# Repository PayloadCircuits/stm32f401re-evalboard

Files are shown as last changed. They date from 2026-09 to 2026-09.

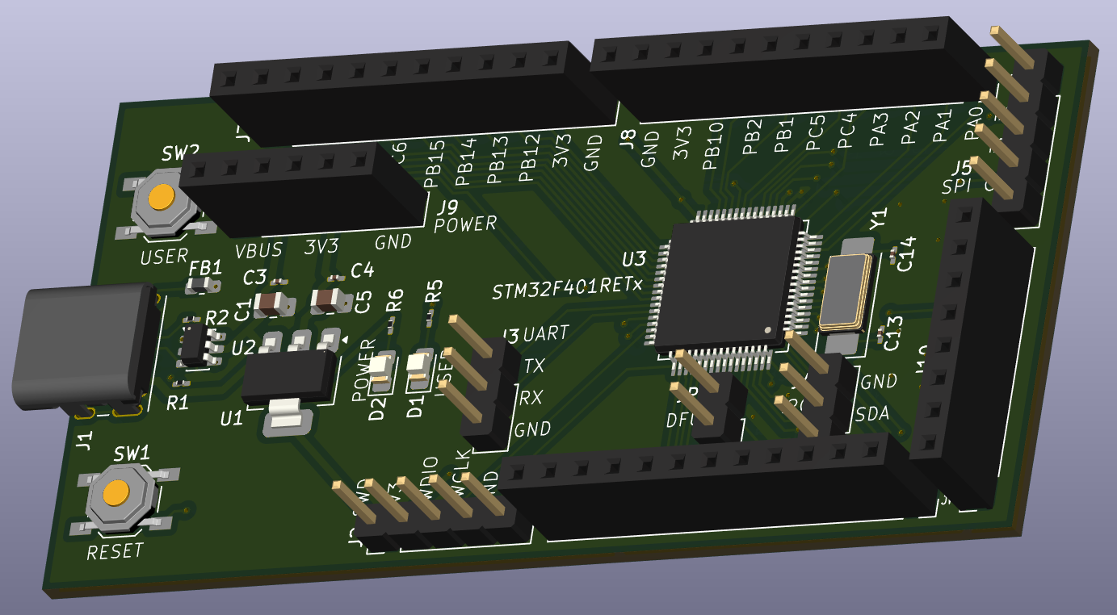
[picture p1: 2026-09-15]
Screenshot 2026-09-03 185238.png

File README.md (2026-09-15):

# STM32F401RE Evaluation Board
Two-layer STM32F401RE (LQFP64) evaluation board designed in KiCad, built as
a solo entry for the **Mixed Traces PCB Design Competition**, hosted by
Mixed Signals (Electronics Association of MEC).

# Overview
A compact, self-contained STM32F401RE dev board inspired by the
NUCLEO-F401RE reference design, built to fit within a 100mm x 100mm,
two-layer PCB. Per the competition rules, an on-board ST-LINK debugger is
not required — programming and debugging are handled through an external
SWD header instead.

## Features
- STM32F401RET6 (LQFP64) microcontroller
- USB-C power input with CC1/CC2 pull-downs and USBLC6-2SC6 ESD protection
- NCP1117-3.3 LDO regulation
- 8MHz HSE crystal (derives both the 84MHz system clock and 48MHz USB clock)
- External SWD header for programming/debugging
- UART, SPI, and I2C headers
- 34 GPIO broken out across four expansion headers, each with 3V3/GND
  reference pins
- Dedicated power breakout header (VBUS, 3V3, GND)
- User + reset buttons, user + power LEDs
- Full ground plane pour on both copper layers

# Tools
Designed entirely in [KiCad](https://www.kicad.org/) 9.

# Schematic
- https://github.com/PayloadCircuits/stm32f401re-evalboard/blob/main/Screenshot%202026-09-03%20185406.png
- https://github.com/PayloadCircuits/stm32f401re-evalboard/blob/main/schematic.pdf

# PCB Layout
https://github.com/PayloadCircuits/stm32f401re-evalboard/blob/main/Screenshot%202026-09-03%20184711.png

# Gerber
https://github.com/PayloadCircuits/stm32f401re-evalboard/blob/main/GERBER.zip

# Render Images
- https://github.com/PayloadCircuits/stm32f401re-evalboard/blob/main/Screenshot%202026-09-03%20185029.png
- https://github.com/PayloadCircuits/stm32f401re-evalboard/blob/main/Screenshot%202026-09-03%20185117.png
- https://github.com/PayloadCircuits/stm32f401re-evalboard/blob/main/Screenshot%202026-09-03%20185238.png

# BOM with estimated component cost
https://github.com/PayloadCircuits/stm32f401re-evalboard/blob/main/BOM%20estimate.pdf

# ERC and DRC results
- https://github.com/PayloadCircuits/stm32f401re-evalboard/blob/main/Screenshot%202026-09-15%20185338.png
- https://github.com/PayloadCircuits/stm32f401re-evalboard/blob/main/Screenshot%202026-09-15%20185429.png

# Status
Entered in the Mixed Traces PCB Design Competition — progress checkpoint
submitted 5 September 2026, final submission due 15 September 2026.

# License
Hardware design files in this repository are licensed under the
[CERN Open Hardware Licence Version 2 - Permissive (CERN-OHL-P-2.0)](LICENSE).

# Author
Adarsh S — [Payload Circuits](https://github.com/PayloadCircuits)

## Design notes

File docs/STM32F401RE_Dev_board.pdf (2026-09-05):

# | Reference Qty | Value | DNP | Exclude from BOM Exclude from Board Footprint Datasheet Description

1 C1,C5,C17 | 3 10uf | Capacitor_SMD:C_0805_2012Metric_Pad1.18x1.45mm_HandSolder ~ | Polarized capacitor
2 C2,C3,C4,C6,C7,C8,C9,C12,C15 9 0.1uf | Capacitor_SMD:C_0201_0603Metric_Pad0.64x0.40mm_HandSolder ~ | Unpolarized capacitor
3 C10 | 1 1uf | Capacitor_SMD:C_0805_2012Metric_Pad1.18x1.45mm_HandSolder ~ | Polarized capacitor
4 C11 | 1 2.2uf | Capacitor_SMD:C_0805_2012Metric_Pad1.18x1.45mm_HandSolder ~ | Unpolarized capacitor
5 C13,C14 | 2 22pf | Capacitor_SMD:C_0201_0603Metric_Pad0.64x0.40mm_HandSolder ~ | Unpolarized capacitor
6 D1 | 1 LED_user | LED_SMD:LED_0805_2012Metric_Pad1.15x1.40mm_HandSolder ~ | Light emitting diode
7 D2 | 1 LED_PWR | LED_SMD:LED_0805_2012Metric_Pad1.15x1.40mm_HandSolder ~ | Light emitting diode
8 FB1,FB2 | 2 FerriteBead_Small | Inductor_SMD:L_0603_1608Metric_Pad1.05x0.95mm_HandSolder ~ | Ferrite bead, small symbol
9 J1 | 1 USB_C_Receptacle_USB2.0_14P | Connector_USB:USB_C_Receptacle_GCT_USB4085 https://www.usb.org/sites/default/files/documents/usb_type-c.zip USB 2.0-only 14P Type-C Receptacle connector
10 J2 | 1 SWD | Connector_PinHeader_1.00mm:PinHeader_1x05_P1.00mm_Vertical ~ | Generic connector, single row, 01x05, script generated
11 J3 | 1 UART | Connector_PinHeader_1.00mm:PinHeader_1x03_P1.00mm_Vertical ~ | Generic connector, single row, 01x03, script generated
12 J4 | 1 I2C | Connector_PinHeader_1.00mm:PinHeader_1x03_P1.00mm_Vertical ~ | Generic connector, single row, 01x03, script generated
13 J5 | 1 SPI | Connector_PinHeader_1.00mm:PinHeader_1x05_P1.00mm_Vertical ~ | Generic connector, single row, 01x05, script generated
14 J6 | 1 GPIO_A | Connector_PinSocket_1.00mm:PinSocket_1x12_P1.00mm_Vertical ~ | Generic connector, single row, 01x12, script generated
15 J7 | 1 GPIO_B | Connector_PinSocket_1.00mm:PinSocket_1x11_P1.00mm_Vertical ~ | Generic connector, single row, 01x11, script generated
16 J8 | 1 GPIO_C | Connector_PinSocket_1.00mm:PinSocket_1x11_P1.00mm_Vertical ~ | Generic connector, single row, 01x11, script generated
17 J9 | 1 POWER | Connector_PinSocket_1.00mm:PinSocket_1x06_P1.00mm_Vertical ~ | Generic connector, single row, 01x06, script generated
18 J10 | 1 GPIO_D | Connector_PinSocket_1.00mm:PinSocket_1x08_P1.00mm_Vertical ~ | Generic connector, single row, 01x08, script generated
19 JP1 | 1 DFU | TestPoint:TestPoint_2Pads_Pitch5.08mm_Drill1.3mm ~ | Jumper, 2-pole, open
20 R1,R2 | 2 5.1K | Resistor_SMD:R_0201_0603Metric_Pad0.64x0.40mm_HandSolder ~ | Resistor
21 R3,R4 | 2 10K | Resistor_SMD:R_0201_0603Metric_Pad0.64x0.40mm_HandSolder ~ | Resistor
22 R5,R6 | 2 470R | Resistor_SMD:R_0201_0603Metric_Pad0.64x0.40mm_HandSolder ~ | Resistor
23 R7,R8 | 2 4.7K | Resistor_SMD:R_0201_0603Metric_Pad0.64x0.40mm_HandSolder ~ | Resistor
24 SW1 | 1 SW_RST | Button_Switch_SMD:SW_SPST_TL3342 ~ | Push button switch, generic, two pins
25 SW2 | 1 SW_user | Button_Switch_SMD:SW_SPST_TL3342 ~ | Push button switch, generic, two pins
26 U1 | 1 NCP1117-3.3_SOT223 | Package_TO_SOT_SMD:SOT-223-3_TabPin2 http://www.onsemi.com/pub_link/Collateral/NCP1117-D.PDF 1A Low drop-out regulator, Fixed Output 3.3V, SOT-223
27 U2 | 1 USBLC6-2SC6 | Package_TO_SOT_SMD:SOT-23-6 https://www.st.com/resource/en/datasheet/usblc6-2.pdf Very low capacitance ESD protection diode, 2 data-line, SOT-23-6
28 U3 | 1 STM32F401RETx | Package_QFP:LQFP-64_10x10mm_P0.5mm https://www.st.com/resource/en/datasheet/stm32f401re.pdf STMicroelectronics Arm Cortex-M4 MCU, 512KB flash, 96KB RAM, 84 MHz, 1.7-3.6V, 50 GPIO, LQFP64
29 Y1 | 1 8MHz | Crystal:Crystal_SMD_0603-2Pin_6.0x3.5mm_HandSoldering ~ | Two pin crystal, small symbol

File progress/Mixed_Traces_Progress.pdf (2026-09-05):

# Mixed Traces PCB Design Competition

## Progress Evaluation Submission — 3 September 2026

## STM32F401RE Evaluation Board

### by Payload Circuits Adarsh S — Solo Entry

## 1. Selected MCU and Design Concept

The fixed microcontroller for this competition is the STM32F401RET6 (LQFP64), as required by the brief. The design concept is a compact, self-contained STM32F401RE evaluation board inspired by the NUCLEO-F401RE reference, built to fit within a 100mm × 100mm, two-layer PCB.

Per the competition rules, the on-board ST-LINK debugger is explicitly not required, which simplified the design considerably compared to the Nucleo reference — programming and debugging are handled through a standard external SWD header rather than an on-board programmer IC. This freed up board area and routing complexity that was redirected toward a more generous GPIO expansion header set.

The design philosophy prioritized correctness and routing/documentation quality (the criteria weighted most heavily in evaluation) over chasing extremes in size or cost, and favored “smart” flexibility — a single, wellexecuted power path and full signal breakout to headers — over redundant ports or power-input options that would add cost and routing complexity without improving the score.

## 2. Block Diagram

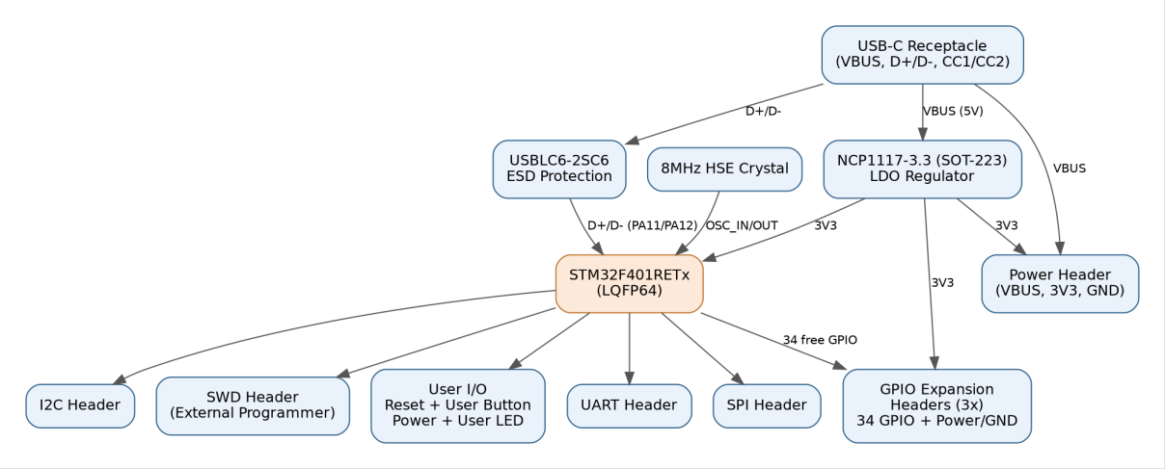
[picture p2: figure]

Figure 1: System block diagram — power, USB, MCU, and header breakout

## 3. Schematic Progress

The schematic is complete and passes ERC with zero unresolved violations.

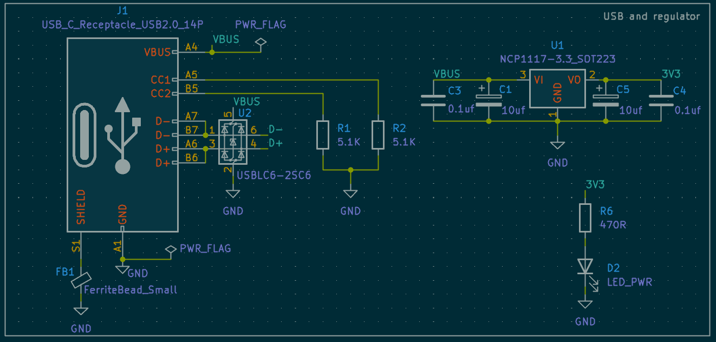
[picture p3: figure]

Figure 2: USB-C input, ESD protection, and 3.3V regulation

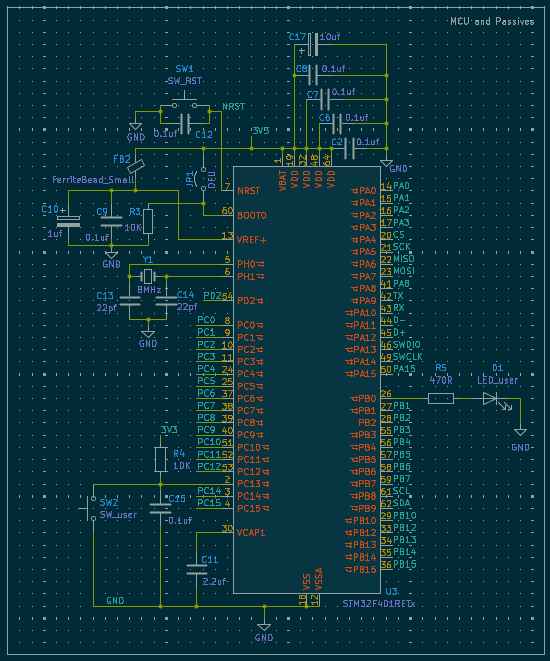
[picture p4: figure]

Figure 3: STM32F401RE core — decoupling, VCAP, reset, BOOT0/DFU, and HSE crystal

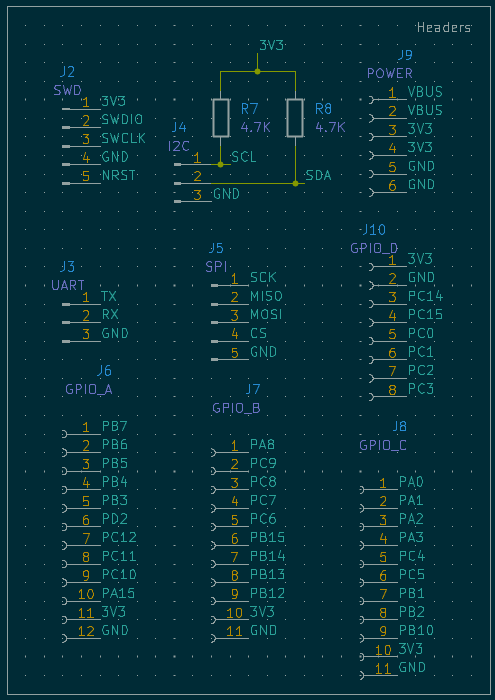
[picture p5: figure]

Figure 4: SWD, UART, SPI, I2C, POWER and GPIO expansion header breakout

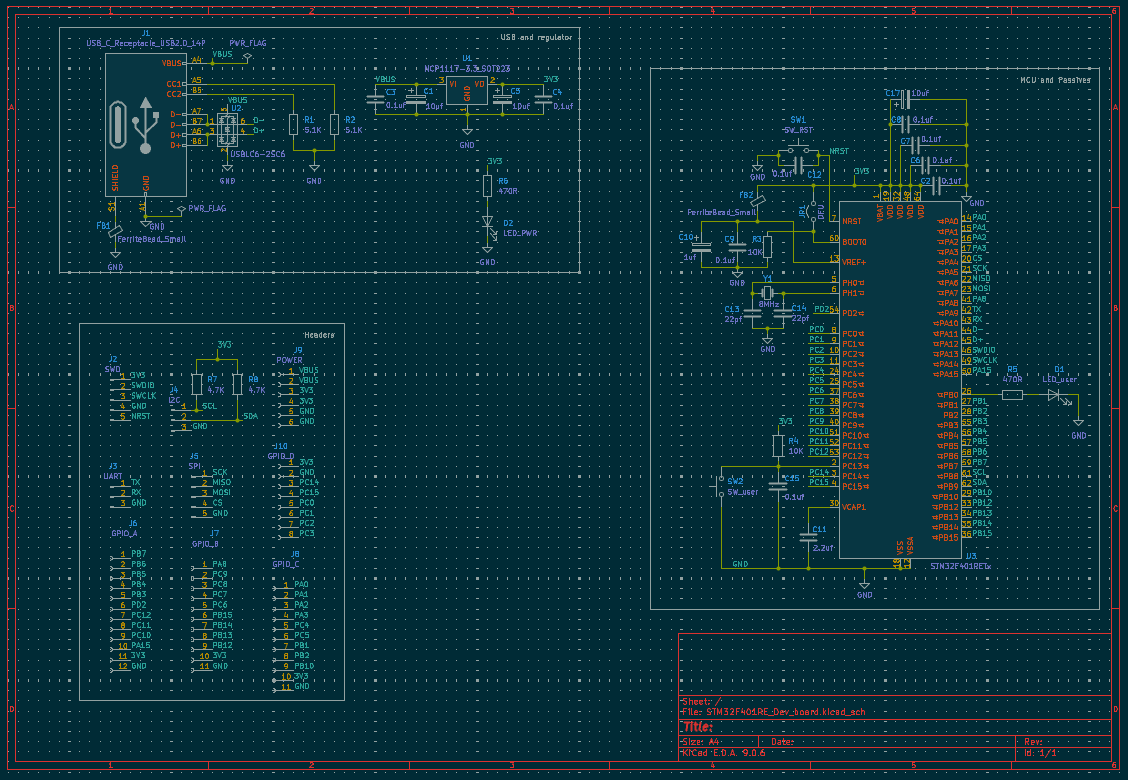
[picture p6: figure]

Figure 5: Complete Schematic diagram

## 4. Component Selection

Key components and the reasoning behind each selection:

Function | Part / Choice | Package | Rationale
MCU | STM32F401RETx | LQFP64 | Fixed by competition rules
Voltage regulator | NCP1117-3.3 (ST suffix) | SOT-223 | Simple fixed-3.3V LDO, adequate for MCU + peripheral current draw, no external feedback network needed
USB connector | USB-C receptacle, full THT (signal + shield legs) | THT, 2-layer footprint | Mechanically robust for repeated insertion; design-only competition so hand-solder ease was not a constraint
USB ESD protection | USBLC6-2SC6 | SOT-23-6 | Low-capacitance ESD array for D+/D-lines, standard practice for USB2.0 device ports
HSE crystal | 8MHz, 22pF load caps | SMD 3.5x6mm, hand-solder | 8MHz cleanly divides/multiplies to both 84MHz SYSCLK and 48MHz USB clock without fractional PLL math
Passives (R, C ≤100nF) | Generic 0603 | 0603 | Compact, consistent footprint across the board
Bulk/decoupling caps (≥1µF) | Generic ceramic | 0805 | Safer margin against DC-bias derating and hand-solder heat vs 0603
Ferrite beads | Generic SMD ferrite bead | 0603 (L_0603_1608Metric)VDD→VDDA analog isolation
Debug/comms/GPIO headers | 2.54mm pitch, male (SWD/UART/SPI/I2C) & female (GPIO/Power) | THT 2.54mm | Male for probe/ribbon-cable connections; female for shield/jumper-wire compatibility, matching Nucleo convention

## 5. PCB Placement / Routing Progress

Component placement is complete, with connectors distributed across all four board edges for accessible wiring, small passives relocated to the bottom layer to relieve top-layer routing density, and the crystal kept
immediately adjacent to the MCU's oscillator pins. Routing is fully complete on both layers with a poured ground plane, and the board passes DRC with zero unresolved violations (a small number of connector-specific clearance flags were reviewed and excluded — see Section 6).

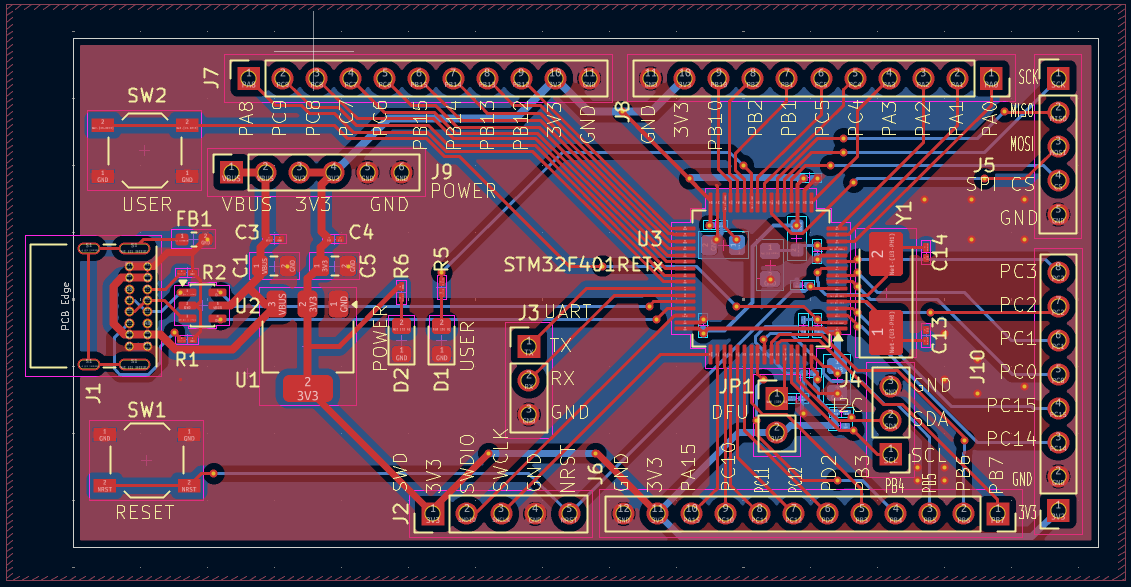
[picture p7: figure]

Figure 5: Completed two-layer routing with ground pour (top view, PCB editor)

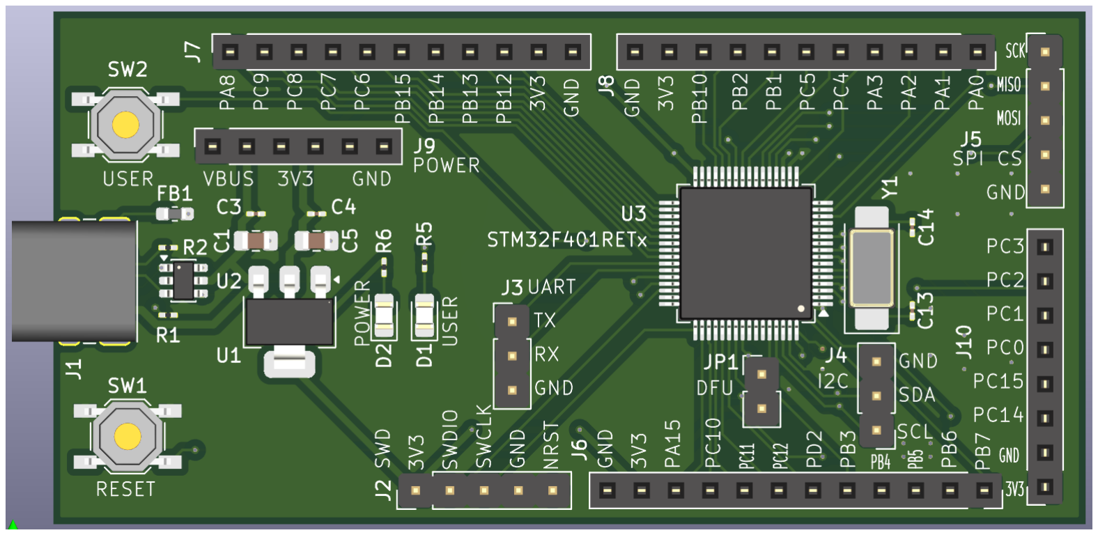
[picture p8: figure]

Figure 6: 3D render, top side

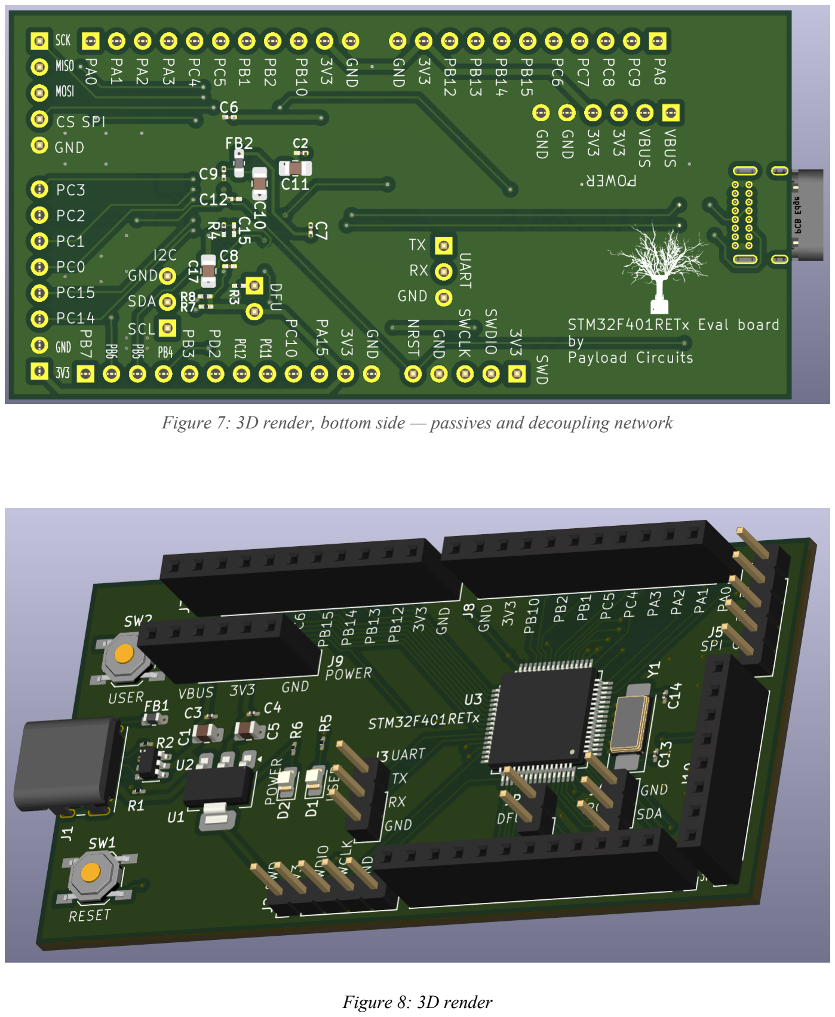
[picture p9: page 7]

Figure 7: 3D render, bottom side — passives and decoupling network

Figure 8: 3D render

## 6. Major Design Decisions

- On-board ST-LINK omitted per competition rules; programming/debugging handled via an external SWD header instead, saving board area and routing for GPIO expansion.
- USB-C power input (no redundant barrel-jack) with CC1/CC2 pull-downs for USB-C power negotiation, keeping the power section simple, low-cost, and low-routing-complexity.
- NCP1117-3.3 in SOT-223 (not SOT-252/DPAK) selected since MCU + peripheral current draw does not need the larger package's added thermal capacity.
- Full through-hole USB-C receptacle (signal and shield legs) chosen over an SMD-only part for greater mechanical durability under repeated cable insertion.
- 8MHz HSE crystal selected specifically because it cleanly derives both the 84MHz system clock and the 48MHz USB clock without fractional PLL configuration.
- All four MCU VDD pins individually decoupled with 100nF capacitors; a single shared 10µF bulk capacitor covers the common VDD net rather than duplicating bulk capacitance at every pin.
- VDDA/VSSA isolated from the main VDD/VSS supply via a ferrite bead on the VDD→VDDA path only, with VSS→VSSA tied directly, following standard STM32 analog-supply practice.
- GPIO expansion split across four headers by port, with 3V3/GND reference pins added to every header — directly satisfying the brief's "power and ground connections through headers" requirement rather than treating it as GPIO-only.
- Small passives (resistors, decoupling/bulk caps, ferrite beads) moved to the bottom copper layer during layout to relieve routing congestion around the MCU on the top layer, while mechanically-interactive parts (connectors, buttons, LEDs, crystal, MCU) remained on top.
- A small number of DRC clearance/thermal-relief flags on the USB-C connector's own footprint (internal pin spacing, F.Fab/Edge.Cuts overlap) were individually reviewed and excluded as expected connector-footprint behavior rather than genuine manufacturing risk; all other violations were resolved by repositioning or adjusting zone connection settings.

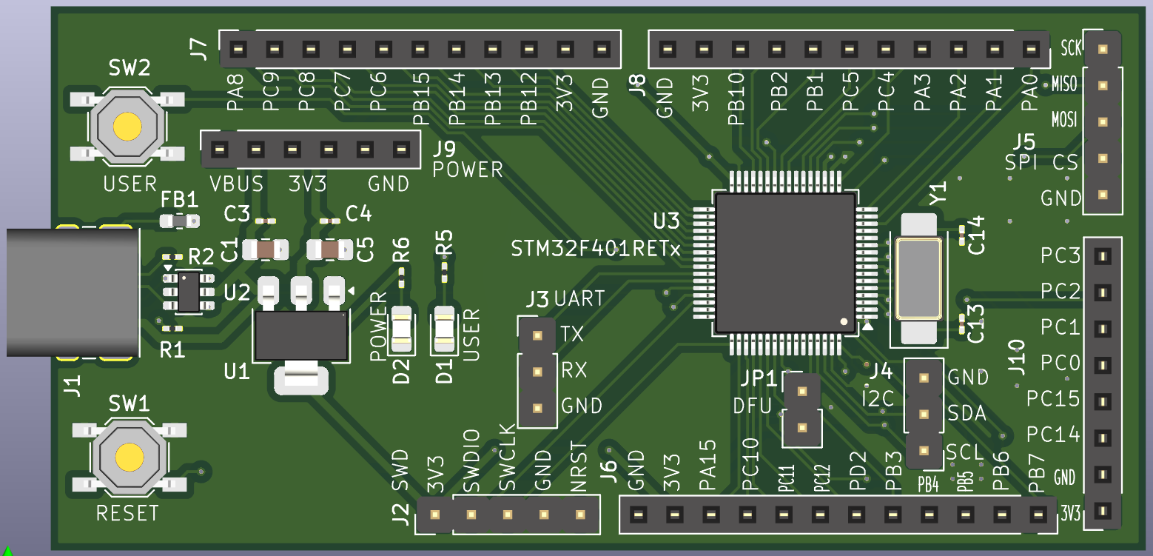
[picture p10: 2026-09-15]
Screenshot 2026-09-03 185029.png

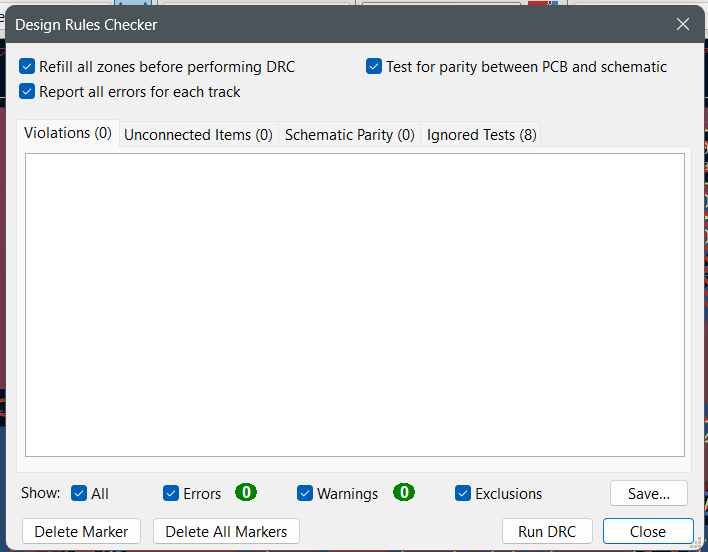
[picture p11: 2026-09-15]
Screenshot 2026-09-15 185429.png

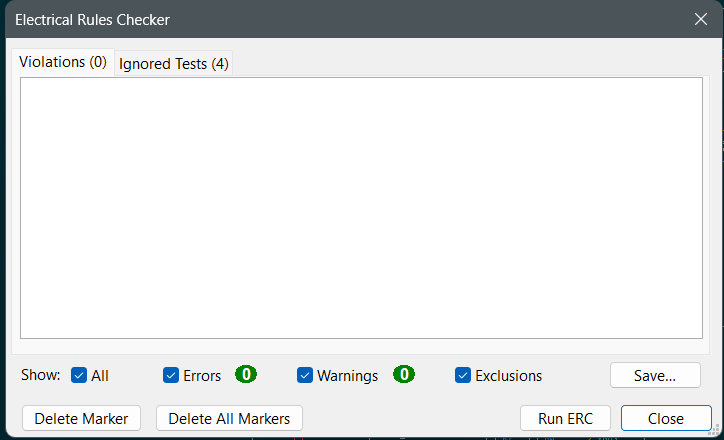
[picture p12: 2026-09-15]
Screenshot 2026-09-15 185338.png

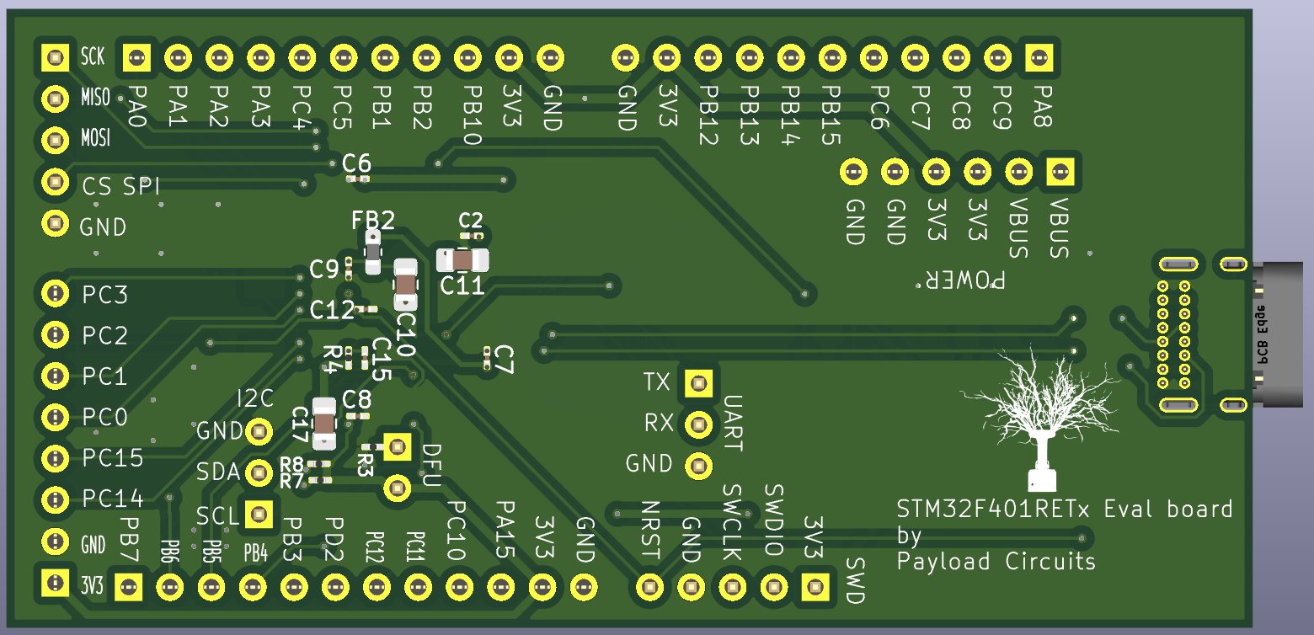
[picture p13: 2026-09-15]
Screenshot 2026-09-03 185117.png

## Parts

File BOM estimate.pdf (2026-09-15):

Id | Designator | Footprint | Quantity Designation | Unit price (₹)
| 1 J2 | PinHeader_1x05_P2.54mm_Vertical | 1 SWD | 10
| 2 C2, C3, C4, C6, C7, C8, C9, C12, C15 | C_0201_0603Metric_Pad0.64x0.40mm_HandSolder | 9 0.1uf | 10
| 3 SW1 | SW_SPST_TL3342 | 1 SW_RST | 55
| 4 U2 | SOT-23-6 | 1 USBLC6-2SC6 | 10
| 5 J10 | PinSocket_1x08_P2.54mm_Vertical | 1 GPIO_D | 10
| 6 C1, C5, C17 | C_0805_2012Metric_Pad1.18x1.45mm_HandSolder | 3 10uf | 15
| 7 SW2 | SW_SPST_TL3342 | 1 SW_user | 55
| 8 Y1 | Crystal_SMD_0603-2Pin_6.0x3.5mm_HandSoldering | 1 8MHz | 60
| 9 R5, R6 | R_0201_0603Metric_Pad0.64x0.40mm_HandSolder | 2 470R | 10
| 10 J6 | PinSocket_1x12_P2.54mm_Vertical | 1 GPIO_A | 10
| 11 FB1, FB2 | L_0603_1608Metric_Pad1.05x0.95mm_HandSolder | 2 FerriteBead_Small | 10
| 12 J7 | PinSocket_1x11_P2.54mm_Vertical | 1 GPIO_B | 10
| 13 J9 | PinSocket_1x06_P2.54mm_Vertical | 1 POWER | 10
| 14 J4 | PinHeader_1x03_P2.54mm_Vertical | 1 I2C | 10
| 15 U3 | LQFP-64_10x10mm_P0.5mm | 1 STM32F401RETx | 350
| 16 J3 | PinHeader_1x03_P2.54mm_Vertical | 1 UART | 10
| 17 R1, R2 | R_0201_0603Metric_Pad0.64x0.40mm_HandSolder | 2 5.1K | 10
| 18 J1 | USB_C_Receptacle_GCT_USB4085 | 1 USB_C_Receptacle_USB2.0_14P | 80
| 19 J5 | PinHeader_1x05_P2.54mm_Vertical | 1 SPI | 10
| 20 D1 | LED_0805_2012Metric_Pad1.15x1.40mm_HandSolder | 1 LED_user | 15
| 21 J8 | PinSocket_1x11_P2.54mm_Vertical | 1 GPIO_C | 10
| 22 D2 | LED_0805_2012Metric_Pad1.15x1.40mm_HandSolder | 1 LED_PWR | 15
| 23 C13, C14 | C_0201_0603Metric_Pad0.64x0.40mm_HandSolder | 2 22pf | 20
| 24 U1 | SOT-223-3_TabPin2 | 1 NCP1117-3.3_SOT223 | 25
| 25 JP1 | PinHeader_1x02_P2.54mm_Vertical | 1 DFU | 10
| 26 C11 | C_0805_2012Metric_Pad1.18x1.45mm_HandSolder | 1 2.2uf | 5
| 27 C10 | C_0805_2012Metric_Pad1.18x1.45mm_HandSolder | 1 1uf | 5
| 28 R3, R4 | R_0201_0603Metric_Pad0.64x0.40mm_HandSolder | 2 10K | 10
| 29 R7, R8 | R_0201_0603Metric_Pad0.64x0.40mm_HandSolder | 2 4.7K | 10

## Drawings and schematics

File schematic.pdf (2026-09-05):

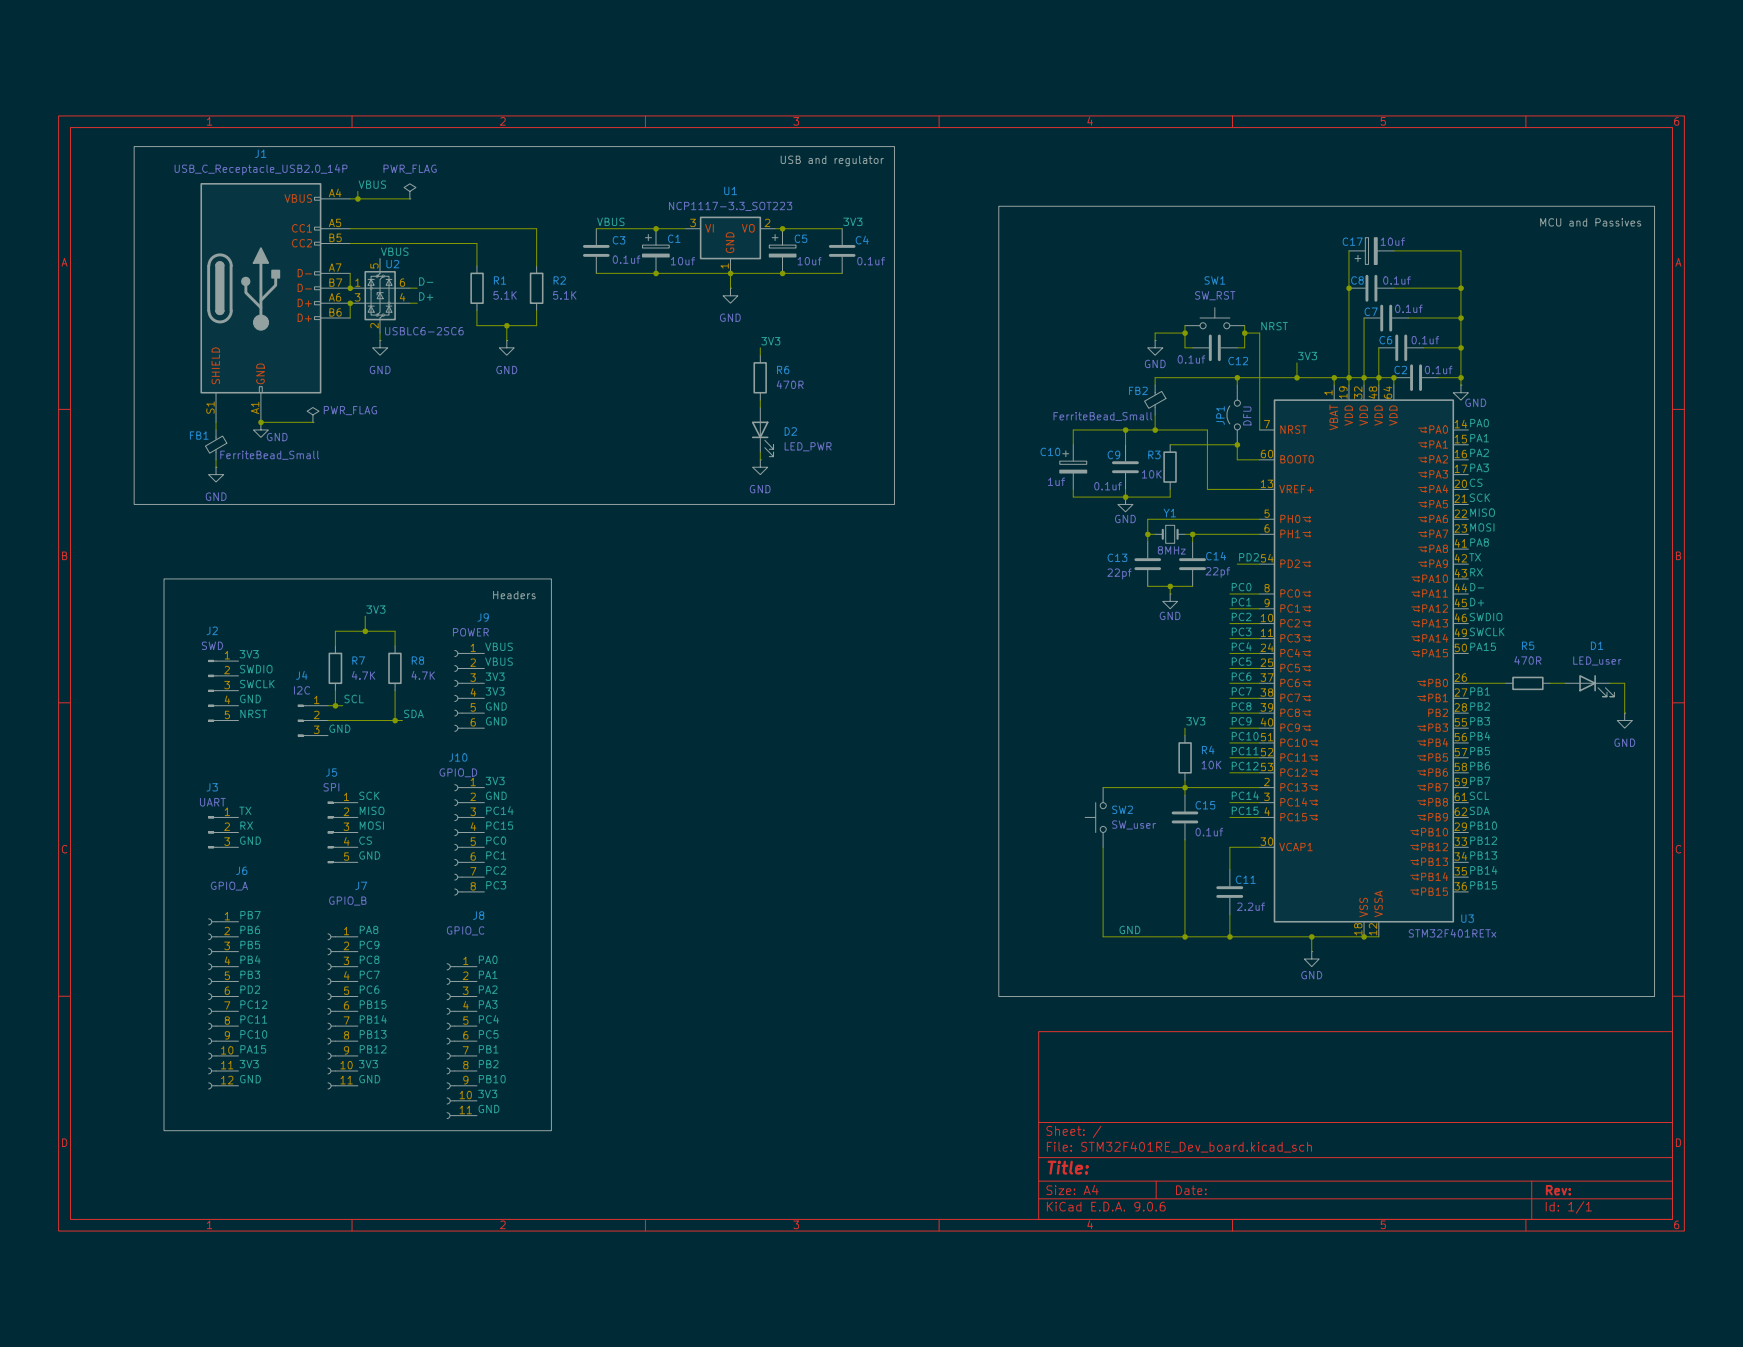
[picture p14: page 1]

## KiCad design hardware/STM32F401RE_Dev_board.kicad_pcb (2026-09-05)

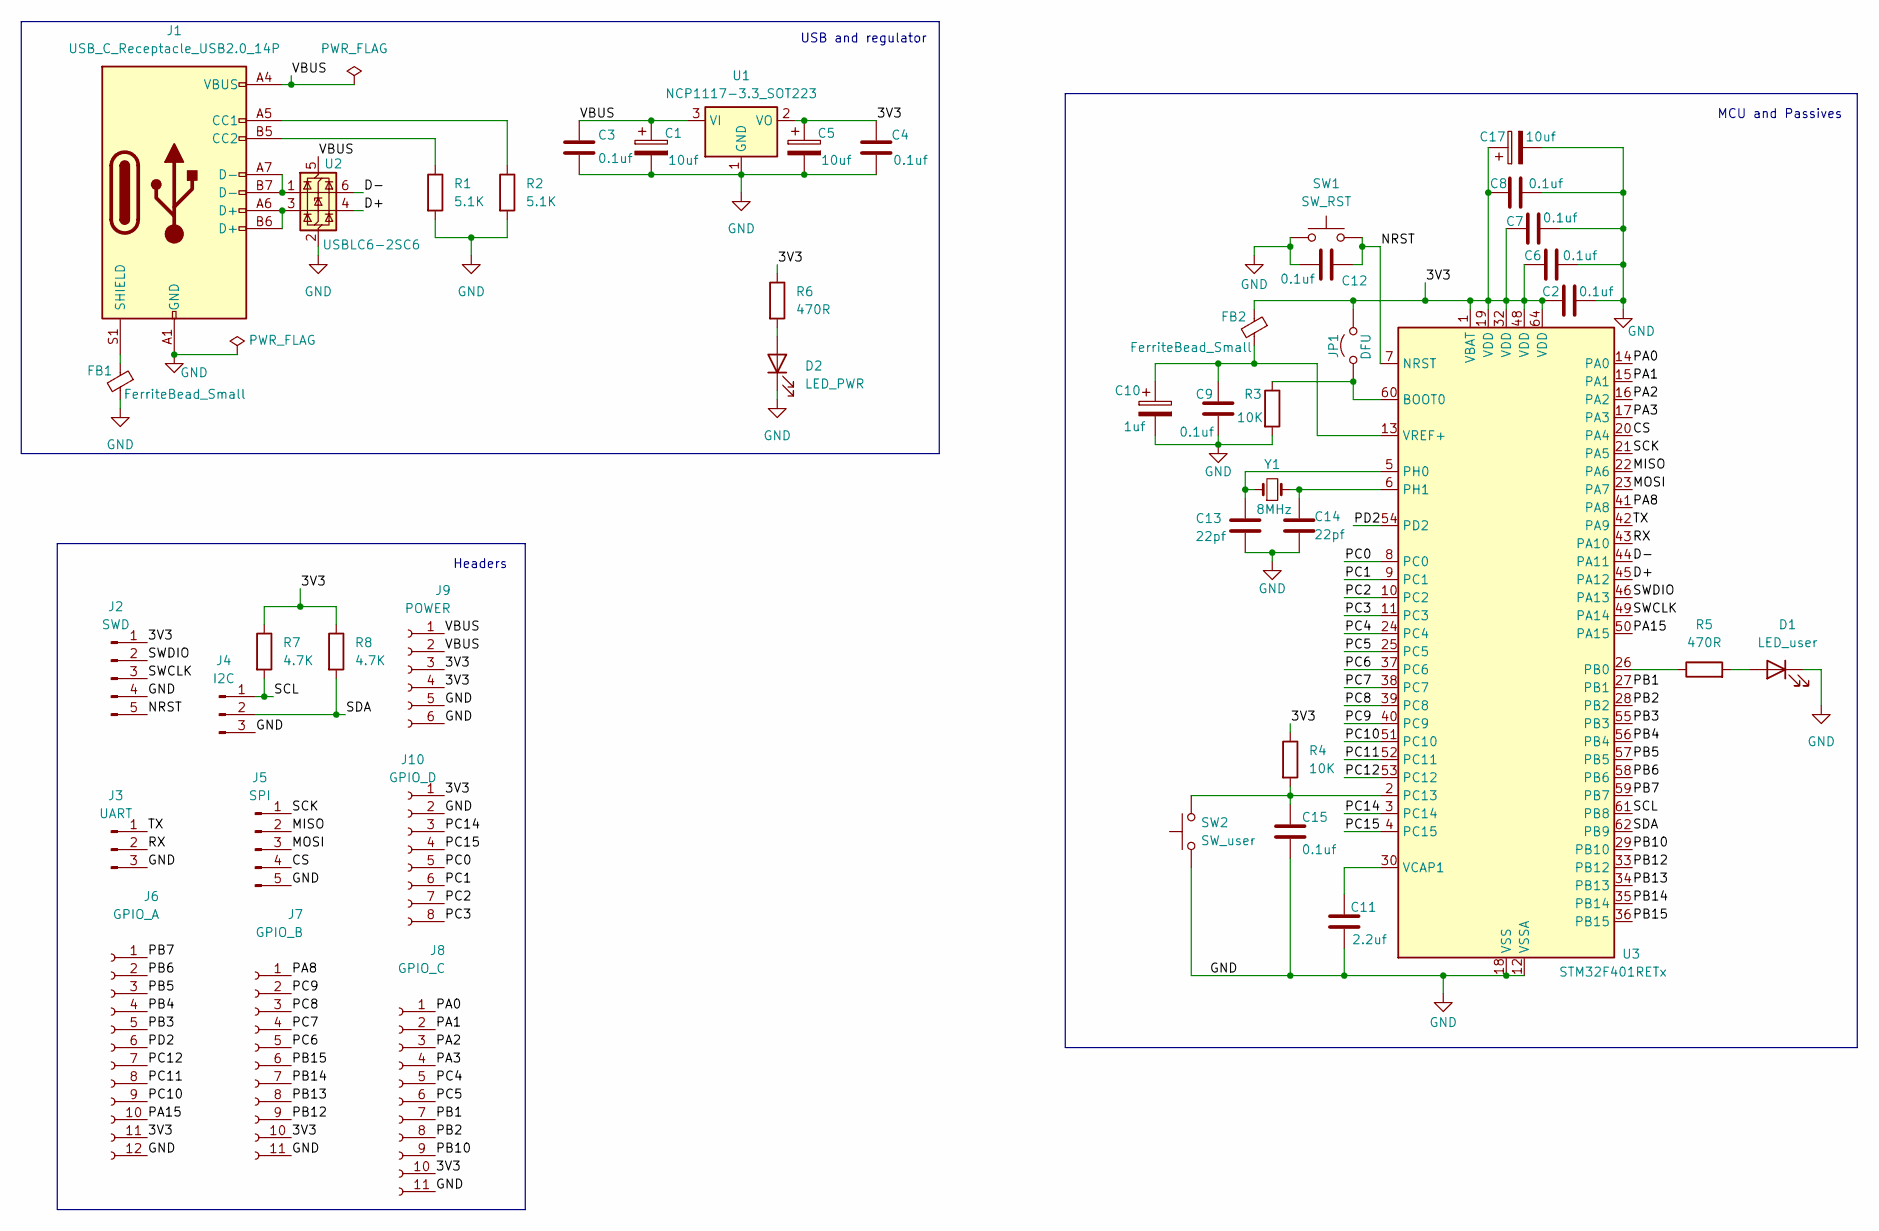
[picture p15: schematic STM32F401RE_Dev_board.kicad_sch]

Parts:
C1, C5, C17: 10uf; C_0805_2012Metric_Pad1.18x1.45mm_HandSolder
C2, C3, C4, C6, C7, C8, C9, C12, C15: 0.1uf; C_0201_0603Metric_Pad0.64x0.40mm_HandSolder
C10: 1uf; C_0805_2012Metric_Pad1.18x1.45mm_HandSolder
C11: 2.2uf; C_0805_2012Metric_Pad1.18x1.45mm_HandSolder
C13, C14: 22pf; C_0201_0603Metric_Pad0.64x0.40mm_HandSolder
D1: LED_user; LED_0805_2012Metric_Pad1.15x1.40mm_HandSolder
D2: LED_PWR; LED_0805_2012Metric_Pad1.15x1.40mm_HandSolder
FB1, FB2: FerriteBead_Small; L_0603_1608Metric_Pad1.05x0.95mm_HandSolder
J1: USB_C_Receptacle_USB2.0_14P; USB_C_Receptacle_GCT_USB4085
J2: SWD; PinHeader_1x05_P2.54mm_Vertical
J3: UART; PinHeader_1x03_P2.54mm_Vertical
J4: I2C; PinHeader_1x03_P2.54mm_Vertical
J5: SPI; PinHeader_1x05_P2.54mm_Vertical
J6: GPIO_A; PinSocket_1x12_P2.54mm_Vertical
J7: GPIO_B; PinSocket_1x11_P2.54mm_Vertical
J8: GPIO_C; PinSocket_1x11_P2.54mm_Vertical
J9: POWER; PinSocket_1x06_P2.54mm_Vertical
J10: GPIO_D; PinSocket_1x08_P2.54mm_Vertical
JP1: DFU; PinHeader_1x02_P2.54mm_Vertical
R1, R2: 5.1K; R_0201_0603Metric_Pad0.64x0.40mm_HandSolder
R3, R4: 10K; R_0201_0603Metric_Pad0.64x0.40mm_HandSolder
R5, R6: 470R; R_0201_0603Metric_Pad0.64x0.40mm_HandSolder
R7, R8: 4.7K; R_0201_0603Metric_Pad0.64x0.40mm_HandSolder
SW1: SW_RST; SW_SPST_TL3342
SW2: SW_user; SW_SPST_TL3342
U1: NCP1117-3.3_SOT223; SOT-223-3_TabPin2
U2: USBLC6-2SC6; SOT-23-6
U3: STM32F401RETx; LQFP-64_10x10mm_P0.5mm
Y1: 8MHz; Crystal_SMD_0603-2Pin_6.0x3.5mm_HandSoldering

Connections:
/3V3: C2.1, C4.1, C5.1, C6.1, C7.1, C8.1, C17.1, FB2.1, J2.1, J6.11, J7.10, J8.10, J9.3, J9.4, J10.1, JP1.2 (B), R4.1, R6.1, R7.1, R8.1, U1.2 (VO), U3.1 (VBAT), U3.19 (VDD), U3.32 (VDD), U3.48 (VDD), U3.64 (VDD)
/CS: J5.4, U3.20 (PA4)
/D+: U2.4 (I/O2), U3.45 (PA12)
/D-: U2.6 (I/O1), U3.44 (PA11)
/MISO: J5.2, U3.22 (PA6)
/MOSI: J5.3, U3.23 (PA7)
/NRST: C12.1, J2.5, SW1.2, U3.7 (NRST)
/PA0: J8.1, U3.14 (PA0)
/PA1: J8.2, U3.15 (PA1)
/PA2: J8.3, U3.16 (PA2)
/PA3: J8.4, U3.17 (PA3)
/PA8: J7.1, U3.41 (PA8)
/PA15: J6.10, U3.50 (PA15)
/PB1: J8.7, U3.27 (PB1)
/PB2: J8.8, U3.28 (PB2)
/PB3: J6.5, U3.55 (PB3)
/PB4: J6.4, U3.56 (PB4)
/PB5: J6.3, U3.57 (PB5)
/PB6: J6.2, U3.58 (PB6)
/PB7: J6.1, U3.59 (PB7)
/PB10: J8.9, U3.29 (PB10)
/PB12: J7.9, U3.33 (PB12)
/PB13: J7.8, U3.34 (PB13)
/PB14: J7.7, U3.35 (PB14)
/PB15: J7.6, U3.36 (PB15)
/PC0: J10.5, U3.8 (PC0)
/PC1: J10.6, U3.9 (PC1)
/PC2: J10.7, U3.10 (PC2)
/PC3: J10.8, U3.11 (PC3)
/PC4: J8.5, U3.24 (PC4)
/PC5: J8.6, U3.25 (PC5)
/PC6: J7.5, U3.37 (PC6)
/PC7: J7.4, U3.38 (PC7)
/PC8: J7.3, U3.39 (PC8)
/PC9: J7.2, U3.40 (PC9)
/PC10: J6.9, U3.51 (PC10)
/PC11: J6.8, U3.52 (PC11)
/PC12: J6.7, U3.53 (PC12)
/PC14: J10.3, U3.3 (PC14)
/PC15: J10.4, U3.4 (PC15)
/PD2: J6.6, U3.54 (PD2)
/RX: J3.2, U3.43 (PA10)
/SCK: J5.1, U3.21 (PA5)
/SCL: J4.1, R7.2, U3.61 (PB8)
/SDA: J4.2, R8.2, U3.62 (PB9)
/SWCLK: J2.3, U3.49 (PA14)
/SWDIO: J2.2, U3.46 (PA13)
/TX: J3.1, U3.42 (PA9)
/VBUS: C1.1, C3.1, J1.A4 (VBUS), J1.A9 (VBUS), J1.B4 (VBUS), J1.B9 (VBUS), J9.1, J9.2, U1.3 (VI), U2.5 (VBUS)
GND: C1.2, C2.2, C3.2, C4.2, C5.2, C6.2, C7.2, C8.2, C9.2, C10.2, C11.2, C12.2, C13.2, C14.2, C15.2, C17.2, D1.1 (K), D2.1 (K), FB1.2, J1.A1 (GND), J1.A12 (GND), J1.B1 (GND), J1.B12 (GND), J2.4, J3.3, J4.3, J5.5, J6.12, J7.11, J8.11, J9.5, J9.6, J10.2, R1.2, R2.2, R3.2, SW1.1, SW2.1, U1.1 (GND), U2.2 (GND), U3.12 (VSSA), U3.18 (VSS), U3.31 (VSS), U3.47 (VSS), U3.63 (VSS)
unnamed: D1.2 (A), R5.2
unnamed: D2.2 (A), R6.2
unnamed: J1.A5 (CC1), R2.1
unnamed: J1.B5 (CC2), R1.1
unnamed: J1.A6 (D+), J1.B6 (D+), U2.3 (I/O2)
unnamed: J1.A7 (D-), J1.B7 (D-), U2.1 (I/O1)
unnamed: FB1.1, J1.S1 (SHIELD)
unnamed: JP1.1 (A), R3.1, U3.60 (BOOT0)
unnamed: R5.1, U3.26 (PB0)
unnamed: C15.1, R4.2, SW2.2, U3.2 (PC13)
unnamed: C13.1, U3.5 (PH0), Y1.1
unnamed: C14.1, U3.6 (PH1), Y1.2
unnamed: C11.1, U3.30 (VCAP1)
unnamed: C9.1, C10.1, FB2.2, U3.13 (VREF+)

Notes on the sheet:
Headers
USB and regulator
MCU and Passives

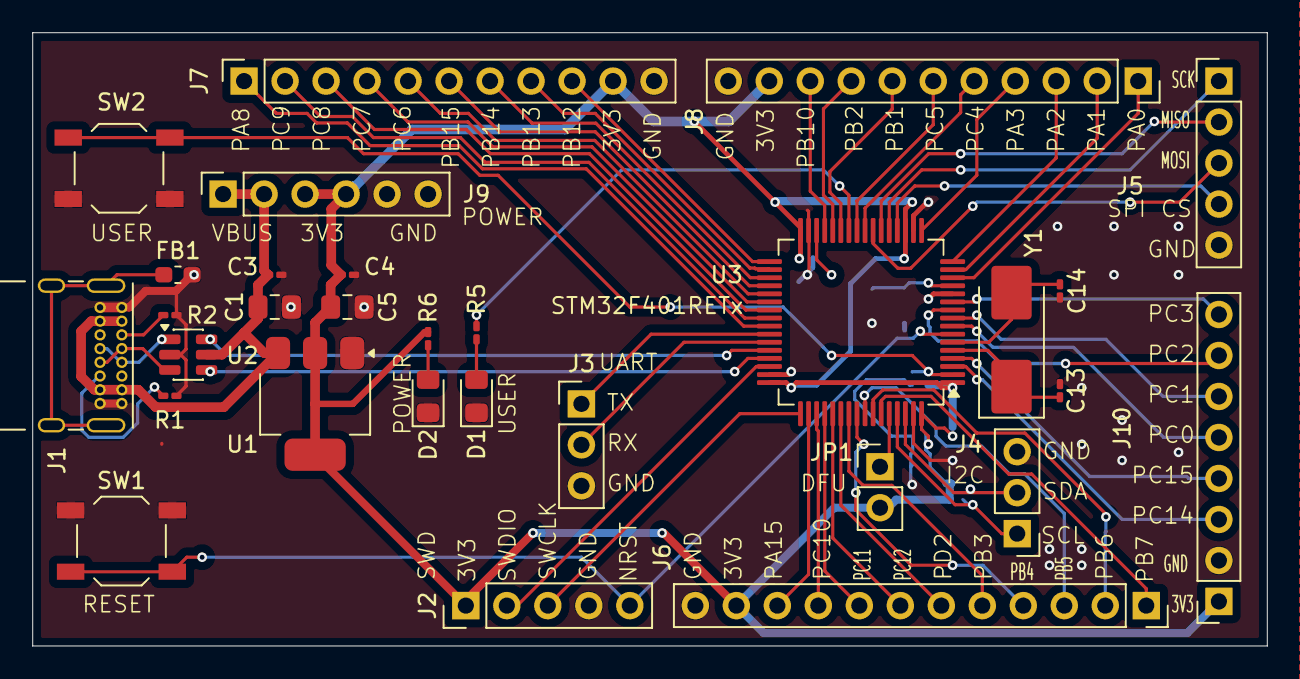
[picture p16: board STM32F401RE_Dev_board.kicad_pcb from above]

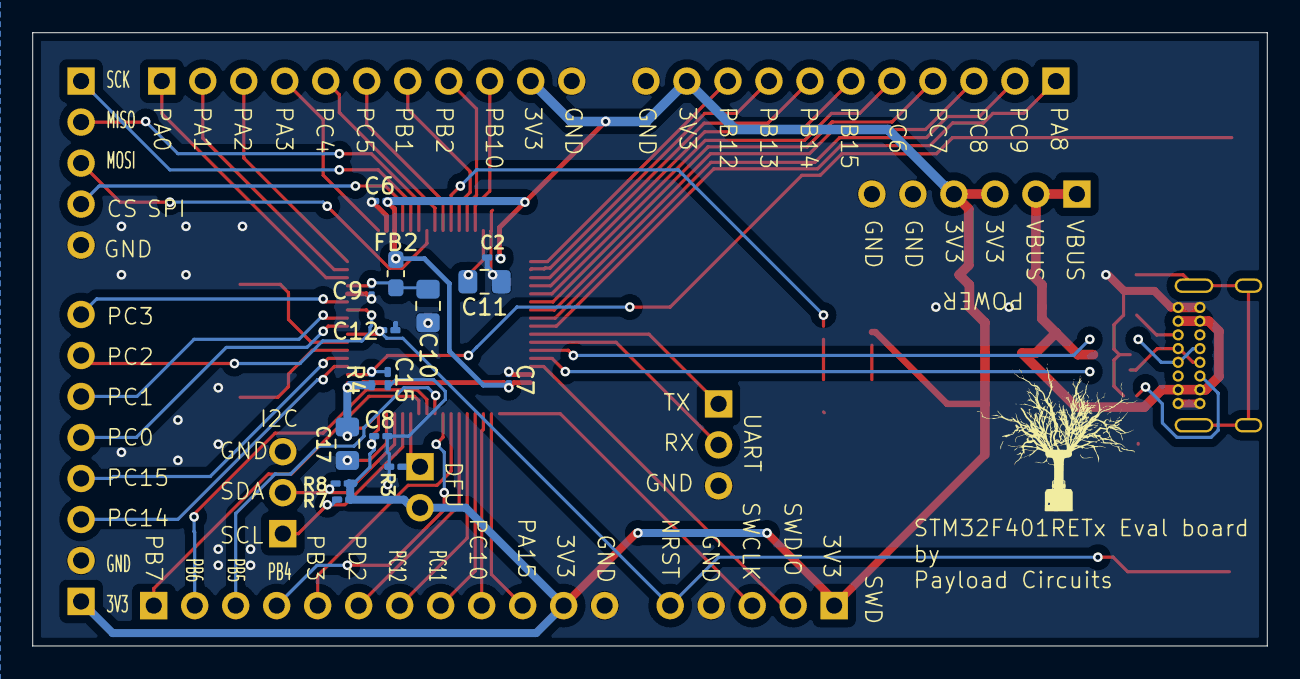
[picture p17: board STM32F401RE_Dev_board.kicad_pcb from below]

Board: 2 copper layers, 76.5 x 38.0 mm, 45 parts (15 on the bottom side), 64 nets.

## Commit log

2026-09-05 Add hardware files, docs, and license
    [STM32F401RE_Dev_board.kicad_pcb, STM32F401RE_Dev_board.kicad_sch]
2026-09-15 Revise README.md with additional project details
    Updated README.md to include new sections for PCB layout, render images, BOM, and ERC/DRC results.
2026-09-15 Add Gerber files link to README
    Added link to Gerber files for the project.
